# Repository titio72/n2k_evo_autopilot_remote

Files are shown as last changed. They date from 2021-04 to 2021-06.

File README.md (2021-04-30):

# EvoAutoPilotRemote
RF remote for Raymarine EVO autopilots

The project uses a ESP32, a CAN adapter MCP2515 and a simple RF receiver to implement a remote command for Raymarine EVO Autopilots.
The remote I've used are simple, cheap EV1527 four buttons 433Mhz that you can find for a few euros on Amazon, Ebay etc.

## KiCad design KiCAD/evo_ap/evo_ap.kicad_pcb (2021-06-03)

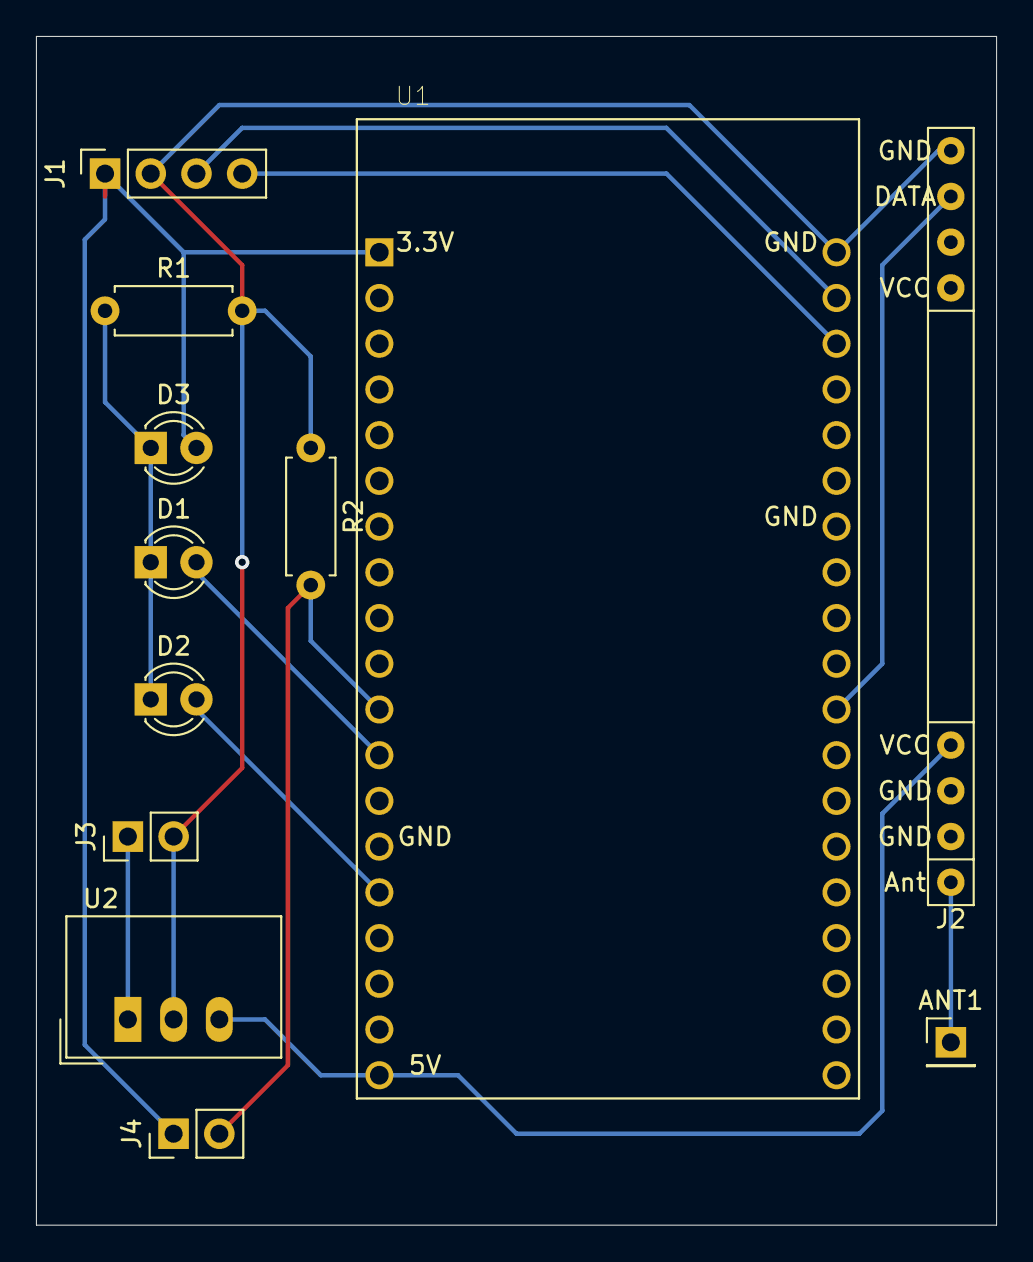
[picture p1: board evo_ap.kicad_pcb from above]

Board: 2 copper layers, 53.3 x 66.0 mm, 12 parts (0 on the bottom side), 12 nets.

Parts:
ANT1: Conn_01x01; PinHeader_1x01_P2.54mm_Vertical
D1, D2, D3: LED; LED_D3.0mm
J1: SN65HVD230_01x04; PinSocket_1x04_P2.54mm_Vertical
J2: RXB6
J3, J4: Conn_01x02; PinHeader_1x02_P2.54mm_Vertical
R1, R2: R; R_Axial_DIN0207_L6.3mm_D2.5mm_P7.62mm_Horizontal
U1: ESP32-DEVKITC-32D; MODULE_ESP32-DEVKITC-32D
U2: TSR_1-2450; Converter_DCDC_TRACO_TSR-1_THT

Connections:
+12V: J3.1, U2.1
GND: J1.2, J2.8, J3.2, R1.2, R2.1, U1.20, U2.2
unnamed: ANT1.1, J2.1
unnamed: D1.1, D2.1, D3.1, R1.1
unnamed: D1.2, U1.12
unnamed: D2.2, U1.15
unnamed: D3.2, J1.1, J4.1, U1.1
unnamed: J1.3, U1.21
unnamed: J1.4, U1.22
unnamed: J2.4, U1.19, U2.3
unnamed: J2.7, U1.30
unnamed: J4.2, R2.2, U1.11

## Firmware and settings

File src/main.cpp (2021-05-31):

#define SINGLE_CLICK_DELAY_THRESHOLD 150
#define AP_STATUS_PIN 14
#define AP_BLINK_PIN 13
#define PROGRAM_PIN 34
#define RADIO_PIN 17

#include <Arduino.h>
#include <EEPROM.h>
#include <Wire.h>
#include <RCSwitch.h>
#include <Adafruit_SSD1306.h>
#include <math.h>
#include "APStatus.h"
#include "EvoN2K.h"
#include "RFUtil.h"
#include "BTInterface.h"
#include "Display.h"

#define EVO_DISPLAY

RCSwitch m = RCSwitch();
APStatus ap = APStatus(AP_STATUS_PIN);
BTInterface bt("ABRemote");
#ifdef EVO_DISPLAY
EVODisplay display;
#endif
unsigned long remote = 0;
bool program = false;

void set_program_mode();

void write_remote_id() {
    Serial.printf("[RM] Wrinting remote %lx to conf\n", remote);
    EEPROM.writeULong(0, remote);
    if (!EEPROM.commit()) {
        Serial.printf("[RM] Failed to write remote code to conf\n");
    }
}

void drawstatus() {
  #ifdef EVO_DISPLAY
  if (program) {
    display.draw_text("Prog");
  } else {
    static char c[32];
    ap.getDescription(c);
    display.draw_text(c);
  }
  #endif
}

void on_status(u_char event) {
  static char buffer[128];
  if (event == 0x02) {
    sprintf(buffer, "[AP] Wind datum {%d}", ap.getWind());
    bt.send_data((uint8_t*)buffer, strlen(buffer));
    if (!program) {
      drawstatus();
    }
  } else if (event == 0x01) {
    sprintf(buffer, "[AP] Locked heading {%d}", ap.getLockedHeading());
    bt.send_data((uint8_t*)buffer, strlen(buffer));
    if (!program) {
      drawstatus();
    }
  } else if (event == 0x10) {
    sprintf(buffer, "[AP] Status {%s} {%d}", ap.getStatusStr(), ap.getStatus());
    bt.send_data((uint8_t*)buffer, strlen(buffer));
    if (!program) {
      drawstatus();
    }
  }
}

const char* on_command(const char* command) {
  Serial.printf("[BT] Received command '%s'\n", command);
  if (strcmp("AUTO", command)==0) {
    EVON2K::switchStatus(AP_AUTO);
    return "OK";
  } else if (strcmp("STANDBY", command)==0) {
    EVON2K::switchStatus(AP_STANDBY);
    return "OK";
  } else if (strcmp("+1", command)==0) {
    EVON2K::port1();
    return "OK";
  } else if (strcmp("+10", command)==0) {
    EVON2K::port10();
    return "OK";
  } else if (strcmp("-1", command)==0) {
    EVON2K::starboard1();
    return "OK";
  } else if (strcmp("-10", command)==0) {
    EVON2K::starboard10();
    return "OK";
  } else if (strcmp("TACKP", command)==0) {
    EVON2K::tackPort();
    return "OK";
  } else if (strcmp("TACKS", command)==0) {
    EVON2K::tackStarboard();
    return "OK";
  } else if (strcmp("HELP", command)==0) {
    return "STATUS: Get the status of the autopilot and the remote\r\n\
AUTO: Switch to compass mode\r\n\
STANDBY: Switch autopilot off\r\n\
[+/-][1/10]: Send +1, -1, +10, -10 key-pressed command\r\n\
+N: Steer startboard\r\n\
-N: Steer port\r\n\
PROG: Enter programming mode";
  } else if (strcmp("STATUS", command)==0) {
    static char response[256];
    sprintf(response, "Mode: %s\r\nPilot: %s\n",
      program?"Program":"Normal",
      ap.getStatusStr());
      return response;
  } else if (strcmp("PROG", command)==0) {
    set_program_mode();
    return "OK";
  } else if (command && (command[0]=='+' || command[0]=='-')) {
    int delta = atoi(command);
    if (delta) EVON2K::setLockedHeading(delta);
    return "OK";
  } else if (strcmp("GOAUTO", command)==0) {
    ap.overrideStatus(AP_AUTO);
    return "OK";
  } else if (strcmp("GOSTANDBY", command)==0) {
    ap.overrideStatus(AP_STANDBY);
    return "OK";
  } else if (strcmp("GOVANE", command)==0) {
    ap.overrideStatus(AP_WIND_VANE);
    return "OK";
  } else if (command && command[0]=='H') {
    int h = atoi(command+1);
    ap.overrideLockedHeading(h);
    return "OK";
  } else if (command && command[0]=='W') {
    int h = atoi(command+1);
    ap.overrideWind(h);
    return "OK";
  } else {
    return "Unknownd command";
  }
}

void read_remote_id() {
  remote = EEPROM.readULong(0);
  Serial.printf("[RM] Read remote %lx from conf\n", remote);
}

void setup() {
  Serial.begin(115200);
  delay(1000);

  bt.set_on_command_callback(on_command);
  bt.begin();

  EEPROM.begin(sizeof(unsigned long)+1);
  read_remote_id();

  m.enableReceive(RADIO_PIN);
  ap.setup(on_status);
  EVON2K::setup(&ap);
  pinMode(AP_BLINK_PIN, OUTPUT);
  pinMode(PROGRAM_PIN, INPUT);


  #ifdef EVO_DISPLAY
  display.setup();
  #endif

  drawstatus();
}

void loop_normal(unsigned long t) {
  static bool led = false;
  static unsigned long led_time = 0;

  static long t0 = 0;
  if (m.available()) {
    digitalWrite(AP_BLINK_PIN, HIGH);
    led = true;
    led_time = t;
    if ((t - t0)>SINGLE_CLICK_DELAY_THRESHOLD) {
      RFUtil r(m.getReceivedValue(), remote);
      Serial.printf("[RF] Received combination %d%d%d%d\n", r.is_A_pressed(), r.is_B_pressed(), r.is_C_pressed(), r.is_D_pressed());
      switch (r.getAction()) {
        case SET_STATUS_ACTION:
          EVON2K::switchStatus(r.get_status());
          break;
        case SET_LOCKED_HEADING_ACTION:
          EVON2K::setLockedHeading(r.get_delta_degrees());
          break;
        case GO_STARBOARD_BY_1_ACTION:
          EVON2K::starboard1();
          break;
        case GO_STARBOARD_BY_10_ACTION:
          EVON2K::starboard10();
          break;
        case GO_PORT_BY_1_ACTION:
          EVON2K::port1();
          break;
        case GO_PORT_BY_10_ACTION:
          EVON2K::port10();
          break;
        case TACK_PORT_ACTION:
          EVON2K::tackPort();
          break;
        case TACK_STARBOARD_ACTION:
          EVON2K::tackStarboard();
          break;
        default:
          break;
      }
    }
    t0 = t;
    m.resetAvailable();
  } else {
    if (led && (t-led_time)>BLINK_TIME) {
      digitalWrite(AP_BLINK_PIN, LOW);
      led = false;
    }
  }
  delay(10);
}

void loop_program(unsigned long t) {
  if (m.available()) {
    remote = m.getReceivedValue() & 0xffff00;
    write_remote_id();
    program = false;
    digitalWrite(AP_BLINK_PIN, LOW);
    printf("[RM] Switching to normal mode.\n");
    drawstatus();
    m.resetAvailable();
    delay(1000);
  } else {
    delay(100);
  }
}

void loop() {
  unsigned long t = millis();
  if (program) {
    loop_program(t);
  } else {
    loop_normal(t);
  }
  if (!program && digitalRead(PROGRAM_PIN)==HIGH) {
    set_program_mode();
  }
  bt.loop(t);
  EVON2K::poll();
}

void set_program_mode() {
    program = true;
    digitalWrite(AP_BLINK_PIN, HIGH);
    drawstatus();
    printf("[RM] Switching to program mode. Click a button to complete.\n");
}

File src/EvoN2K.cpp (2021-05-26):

// use this block with esp and transceiver
#define USE_N2K_CAN USE_N2K_ESP32_CAN
#define ESP32_CAN_RX_PIN GPIO_NUM_23
#define ESP32_CAN_TX_PIN GPIO_NUM_22

// use this block with MCP2515
//#define USE_N2K_CAN USE_N2K_MCP_CAN
//#define N2k_SPI_CS_PIN 5
//#define N2k_CAN_INT_PIN 0xff
//#define USE_MCP_CAN_CLOCK_SET 8

#define DEST 204
#define SOURCE 23

enum key_codes {
  KEY_PLUS_1 = 0x07f8,
  KEY_PLUS_10 = 0x08f7,
  KEY_MINUS_1 = 0x05fa,
  KEY_MINUS_10 = 0x06f9,
  KEY_MINUS_1_MINUS_10 = 0x21de,
  KEY_PLUS_1_PLUS_10 = 0x22dd,
  KEY_TACK_PORTSIDE = KEY_MINUS_1_MINUS_10,
  KEY_TACK_STARBORD = KEY_PLUS_1_PLUS_10
};

//#define DEBUG_AP

#include <Arduino.h>
#include <NMEA2000_CAN.h>
#include <RCSwitch.h>
#include <N2kMessages.h>
#include <math.h>

#include "EvoN2K.h"
#include "APStatus.h"

const unsigned long TransmitMessages[] PROGMEM = {126208UL,   // Set Pilot Mode
                                                  126720UL,   // Send Key Command
                                                  65288UL,    // Send Seatalk Alarm State
                                                  0
                                                 };

const unsigned long ReceiveMessages[] PROGMEM = { 127250UL,   // Read Heading
                                                  65288UL,    // Read Seatalk Alarm State
                                                  65379UL,    // Read Pilot Mode
                                                  65360UL,    // Read Pilot locked head
                                                  0
                                                };


APStatus* status = NULL;
int request_locked_heading = -1;
unsigned long lastHeadTime = 0;

void EVON2K::switchStatus(int s) {
  tN2kMsg m;
  m.Init(2, 126208, SOURCE, DEST);
  u_char b[] = {
                    0x01,  // 126208 type (1 means "command")
                    0x63,  // PGN 65379
                    0xff,  // PGN 65379
                    0x00,  // PGN 65379
                    0xf8,  // priority + reserved
                    0x04,  // 4 params
                    0x01,  // first param - 1 of PGN 65379 (manufacturer code)
                    0x3b,  // 1851 Raymarine
                    0x07,  // 1851 Raymarine
                    0x03,  // second param -  3 of pgn 65369 (Industry code)
                    0x04,  // Ind. code 4
                    0x04,  // third parameter - 4 of pgn 65379 (mode)
                    0x00,  // code 0 (STDBY)
                    0x00,  // fourth param - 0 (does not exists, seems to be a Raymarine hack)
                    0x05   // value of weird raymarine param
  };
  if (s==AP_AUTO) b[12] = 0x40;
  for (int i = 0; i<15; i++) m.AddByte(b[i]);
  bool res = NMEA2000.SendMsg(m);
  Serial.printf("[NT] Switching pilot %s {%s}\n", (s==AP_AUTO)?"On":"Off", res?"Ok":"Ok");

  #ifdef DEBUG_AP
  status->overrideStatus((s==AP_AUTO)?AP_AUTO:AP_STANDBY);
  #endif
}

int EVON2K::setLockedHeading(int delta) {
  if (status->getStatus()!=AP_AUTO) {
      Serial.printf("[NT] Unsupported status (only AUTO [0] is supported): %d\n", status->getStatus());
      return -9;
  } else if (request_locked_heading==-1) {
    if (status->getLockedHeading()==-1) {
      Serial.printf("[NT] Set pilot heading error: %s\n", "no value for locked heading");
      return -1;
    } else {
      // initialize the request with th current value of the "locked head" of the AP
      request_locked_heading = status->getLockedHeading();
    }
  }

  lastHeadTime = time(0);

  int oldRequest = request_locked_heading;
  request_locked_heading += delta;
  request_locked_heading = (request_locked_heading + 360) % 360;
  double rads = DegToRad(request_locked_heading);
  long lHeading = (long)round(rads / 0.0001);

  u_char byte0 = (u_char) (lHeading & 0xff);
  u_char byte1 = (u_char) ((lHeading >> 8) & 0xff);

  u_char b[] = {
                0x01,
                0x50, // pgn 65360
                0xff, // pgn 65360
                0x00, // pgn 65360
                0xf8, // priority + reserved
                0x03, // n params
                0x01, 0x3b, 0x07, // param 1
                0x03, 0x04, // param 2
                0x06, byte0, byte1 // param 3: heading
  };
  tN2kMsg m;
  m.Init(2, 126208, SOURCE, DEST);
  for (int i = 0; i<14; i++) m.AddByte(b[i]);
  bool res = NMEA2000.SendMsg(m);
  if (res) {
    Serial.printf("[NT] Set pilot heading %d (%d) {Ok}\n", request_locked_heading, oldRequest);
  } else {
    request_locked_heading = oldRequest;
    Serial.printf("[NT] Set pilot heading error {Ko}\n");
  }
  return 0;
}

void on_msg(const tN2kMsg &msg) {
    status->onPGN(msg);
}

void EVON2K::setup(APStatus* s) {
  request_locked_heading = -1;
  lastHeadTime = 0;
  status = s;
  Serial.printf("[NT] Initializing N2K\n");
  NMEA2000.ExtendReceiveMessages(NULL);
  NMEA2000.SetN2kCANReceiveFrameBufSize(200);
  NMEA2000.SetN2kCANMsgBufSize(16);
  NMEA2000.SetProductInformation("00000001", 100,
                                /*12345678901234567890123456789012*/
                                 "ABRemote                        ", "1.0.0.0 (2021-05-01)", "1.0.0.0 (2021-05-01)"
                                 );
  NMEA2000.SetDeviceInformation(1, /*Unique number. Use e.g. Serial number.*/ 150 /* Autopilot */, 40 /* Steering */, 2047);
  NMEA2000.SetMode(tNMEA2000::N2km_ListenAndSend, SOURCE);
  NMEA2000.ExtendTransmitMessages(TransmitMessages);
  NMEA2000.ExtendReceiveMessages(ReceiveMessages);
  NMEA2000.EnableForward(false);
  NMEA2000.SetMsgHandler(on_msg);
  bool initialized = NMEA2000.Open();
  Serial.printf("[NT] Initialized N2K {%s}\n", initialized?"Ok":"Ko");

}

void resetHeading() {
  if (request_locked_heading!=-1) {
    long now = time(0);
    if ((now-lastHeadTime)>5) {
      request_locked_heading = -1;
      Serial.printf("[NT] reset pilot heading\n");
    }
  }
}

void EVON2K::poll() {
  NMEA2000.ParseMessages();
  resetHeading();
}

static boolean KeyCommand(uint16_t command) {
  tN2kMsg m;
  m.Init(2, 126720UL, SOURCE, DEST);

  u_char commandByte0, commandByte1;
  commandByte0 = command >> 8;
  commandByte1 = command & 0xff;
  u_char buffer[] = {
    0x3b, 0x9f, 0xf0, 0x81, 0x86, 0x21, commandByte0, commandByte1,
    0xff, 0xff, 0xff, 0xff, 0xff, 0xc1, 0xc2, 0xcd,
    0x66, 0x80, 0xd3, 0x42, 0xb1, 0xc8
  };
  for (int i = 0; i<22; i++) m.AddByte(buffer[i]);

  return NMEA2000.SendMsg(m);
}

void EVON2K::starboard1() {
  bool b = KeyCommand(KEY_PLUS_1);
  Serial.printf("[NT] Go starboard by 1 {%s}\n", b?"Ok":"Ko");
}

void EVON2K::starboard10() {
  bool b = KeyCommand(KEY_PLUS_10);
  Serial.printf("[NT] Go starboard by 10 {%s}\n", b?"Ok":"Ko");
}

void EVON2K::port1() {
  bool b = KeyCommand(KEY_MINUS_1);
  Serial.printf("[NT] Go port by 1 {%s}\n", b?"Ok":"Ko");
}

void EVON2K::port10() {
  bool b = KeyCommand(KEY_MINUS_10);
  Serial.printf("[NT] Go port by 10 {%s}\n", b?"Ok":"Ko");
}
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

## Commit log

2021-05-26 Added support to oled display
    [evo_ap.kicad_pcb, evo_ap.sch]
2021-06-03 Schema update using MCP2562
    [evo_ap.kicad_pcb, evo_ap.sch]
